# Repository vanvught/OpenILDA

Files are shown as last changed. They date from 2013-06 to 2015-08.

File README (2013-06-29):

---> WORK IN PROGRESS <---

OpenILDA
========

Cheap ILDA SPI DAC board for Raspberry Pi. 

ILDA output: balanced X/Y - 12 bit,  balanced R/G/B/I - 8 bit.

Playback of ILDA files from external SD card.

OSC support (using RPi <- UART/USB -> PC[java] <- UDP-> iPad/iPod)

This OpenILDA DAC board uses the SPI interface for controlling 3 DAC's. The MCP49x2 device is a dual channel DAC.
As the RPi just has 2 SPI chip enable lines, the DAC /CS lines are created by using a HC139 See viewtopic.php?p=333992#p333992

Of course, I could have used a 12-bit 8-channel DAC (for example TLV5610IDW). This would create less components. However, such a DAC is relatively expensive (24 Euro) and it would have a SO-20 package.

I will post the OpenILDA sd-card player with OSC support (written for bare-metal) soon.

What's next? ()
*. Reduce the amount of OPAMP's (from 6 to 3)
*. Enable using single voltage power supply
	- Use DC/DC converter for -12 volt / +12 volt
	- Use 7805 for 5 volt output voltage
	
See also http://www.raspberrypi.org/phpBB3/viewtopic.php?p=366647#p366647

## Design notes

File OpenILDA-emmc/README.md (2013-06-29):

FILES
  ffconf.h   Configuration file for FatFs module.
  ff.h       Common include file for FatFs and application module.
  ff.c       FatFs module.
  diskio.h   Common include file for FatFs and disk I/O modul.
  diskio.c   An example of glue function to attach existing disk I/O module to FatFs.
  integer.h  Integer type definitions for FatFs.

  bcm2835.c  Mike's library ported for bare-metal
  mmcbb.c    Low level disk I/O module for Rasberry Pi
  vectors.s  Copyright (c) 2012 David Welch dwelch@dwelch.com
  syscalls.c Support file for GNU libc.  

AGREEMENTS

FatFs module is an open source software to implement FAT file system to
small embedded systems. This is a free software and is opened for education,
research and commercial developments under license policy of following trems.

Copyright (C) 2012, ChaN, all right reserved.

 * The FatFs module is a free software and there is NO WARRANTY.
 * No restriction on use. You can use, modify and redistribute it for
   personal, non-profit or commercial product UNDER YOUR RESPONSIBILITY.
 * Redistributions of source code must retain the above copyright notice.

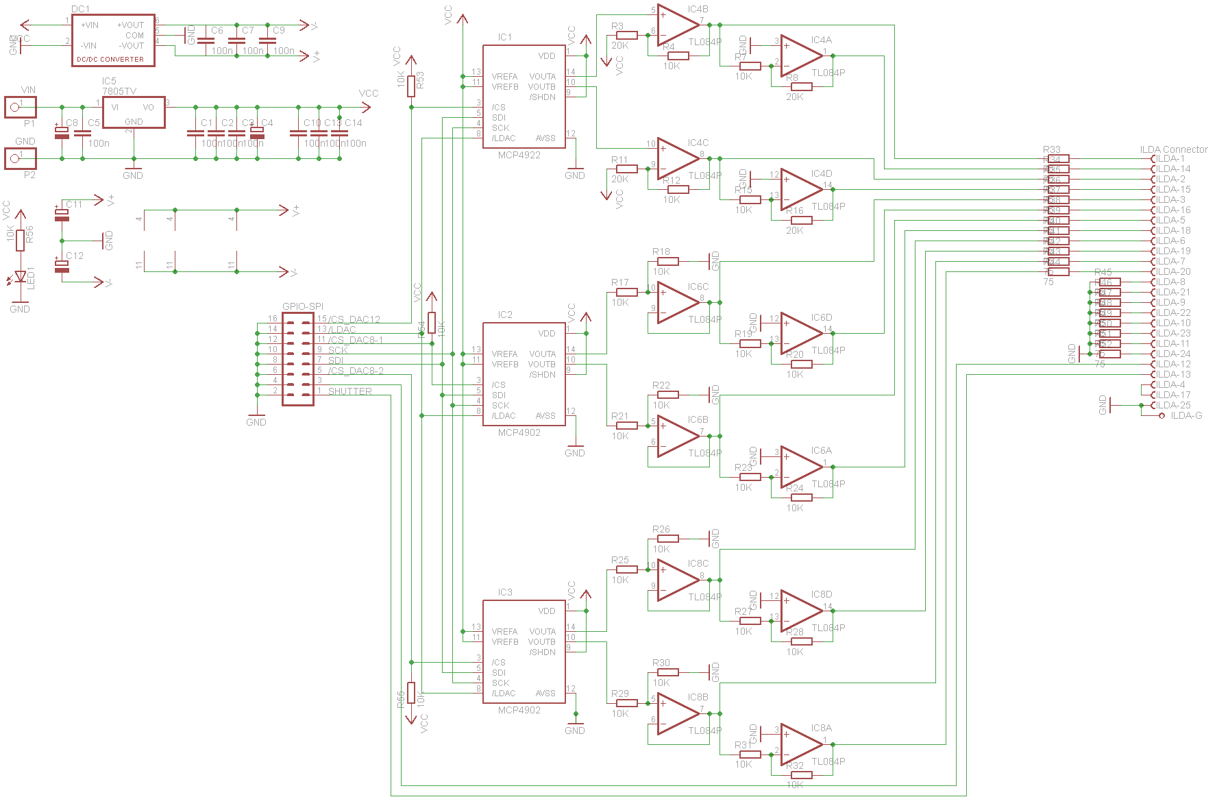
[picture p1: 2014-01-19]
Eagle/Rpi-ILDA-DAC_sch.png

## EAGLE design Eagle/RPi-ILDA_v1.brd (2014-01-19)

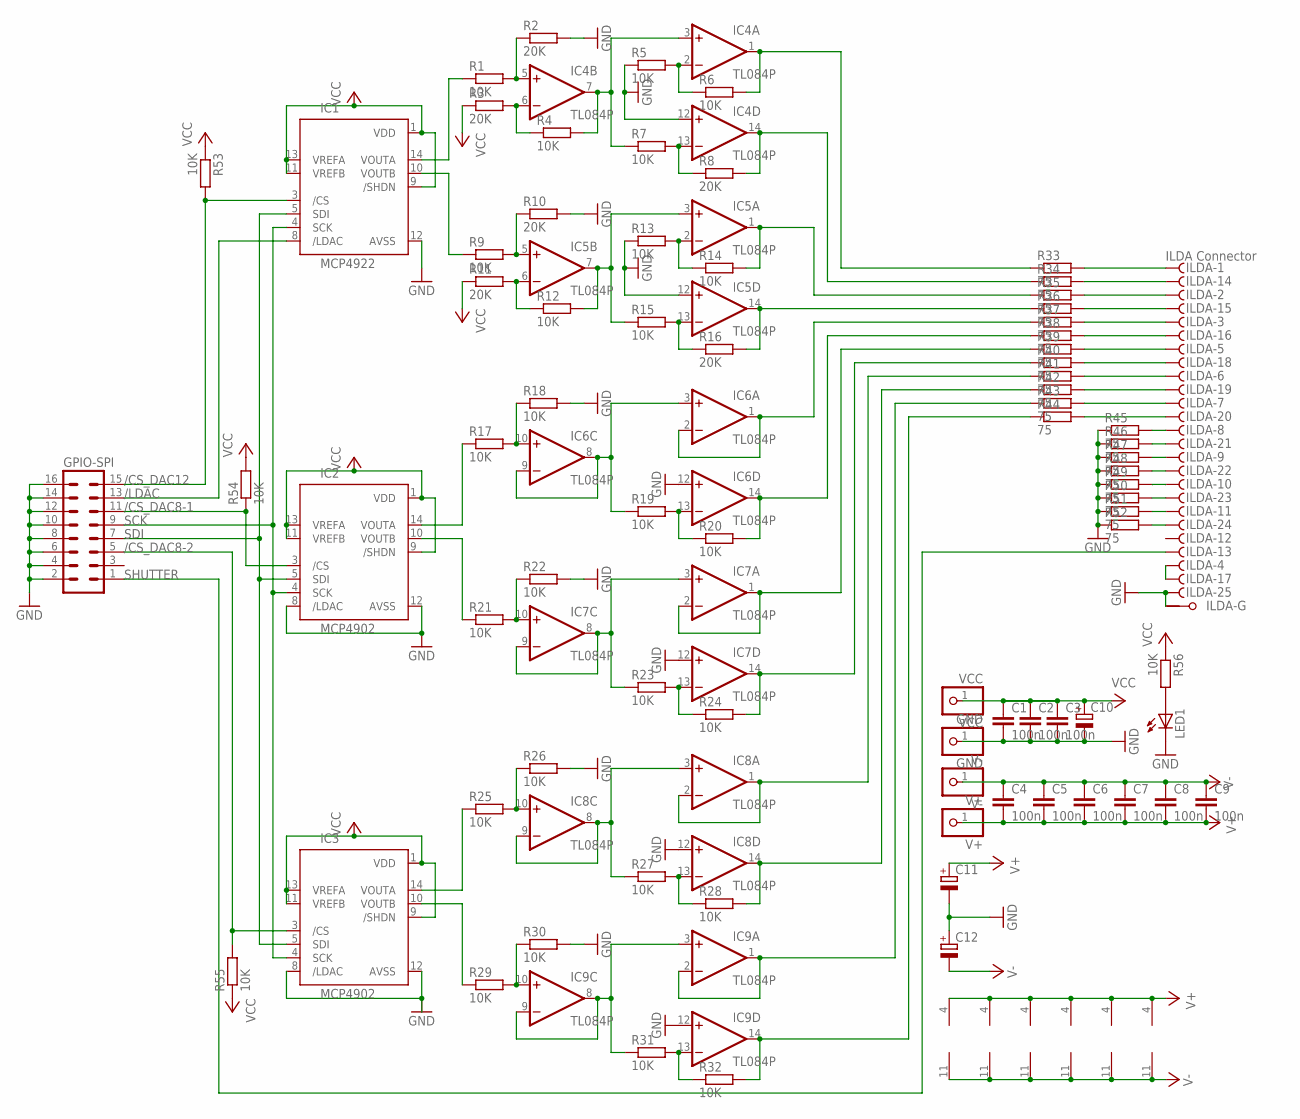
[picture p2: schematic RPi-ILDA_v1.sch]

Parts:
C1, C2, C3, C4, C5, C6, C7, C8, C9: 100n; C050-024X044
C10, C11, C12: CPOL-EUE5-6; E5-6
GND: GND; 1X01
GPIO-SPI: MA08-2
IC1: MCP4922; DIL14
IC2, IC3: MCP4902; DIL14
IC4, IC5, IC6, IC7, IC8, IC9: TL084P; DIL14
ILDA: ILDA Connector; F25HP
LED1: LED3MM
R1, R7, R9, R15, R17, R21, R22, R25, R29, R30, R53, R54, R55: 10K; 0204/5
R2, R8, R10, R16: 20K; 0204V
R3, R11: 20K; 0204/5
R4, R5, R6, R12, R13, R14, R18, R19, R20, R23, R24, R26, R27, R28, R31, R32, R56: 10K; 0204V
R33, R34, R35, R36, R37, R38, R39, R40, R41, R42, R43, R44, R45, R46, R47, R48, R49, R50, R51, R52: 75; 0204V
V+: V+; 1X01
V-: V-; 1X01
VCC: VCC; 1X01

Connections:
/CS_DAC8-1: GPIO-SPI.11, IC2.3 (/CS), R54.1
/CS_DAC8-2: GPIO-SPI.5, IC3.3 (/CS), R55.2
/CS_DAC12: GPIO-SPI.15, IC1.3 (/CS), R53.2
/LDAC: GPIO-SPI.13, IC1.8 (/LDAC)
GND: C1.2, C2.2, C3.2, C10.-, C11.-, C12.+, GND.1, GPIO-SPI.2, GPIO-SPI.4, GPIO-SPI.6, GPIO-SPI.8, GPIO-SPI.10, GPIO-SPI.12, GPIO-SPI.14, GPIO-SPI.16, IC1.12 (AVSS), IC2.8 (/LDAC), IC2.12 (AVSS), IC3.8 (/LDAC), IC3.12 (AVSS), IC4.12 (+IN), IC5.12 (+IN), IC6.12 (+IN), IC7.12 (+IN), IC8.12 (+IN), IC9.12 (+IN), ILDA.25 (F), ILDA.G1, LED1.K (C), R2.2, R5.1, R10.2, R13.1, R18.2, R22.2, R26.2, R30.2, R45.1, R46.1, R47.1, R48.1, R49.1, R50.1, R51.1, R52.1
unnamed: LED1.A, R56.2
unnamed: ILDA.3 (F), R37.2
unnamed: IC4.2 (-IN), R5.2, R6.1
unnamed: IC5.2 (-IN), R13.2, R14.1
unnamed: IC5.13 (-IN), R15.2, R16.1
unnamed: IC3.14 (VOUTA), R25.1
unnamed: IC7.14 (OUT), R24.2, R40.1
unnamed: IC7.13 (-IN), R23.2, R24.1
unnamed: IC7.10 (+IN), R21.2, R22.1
unnamed: ILDA.4 (F), ILDA.17 (F)
unnamed: IC7.3 (+IN), IC7.8 (OUT), IC7.9 (-IN), R23.1
unnamed: IC7.1 (OUT), IC7.2 (-IN), R39.1
unnamed: ILDA.5 (F), R39.2
unnamed: IC1.14 (VOUTA), R1.1
unnamed: IC1.10 (VOUTB), R9.1
unnamed: ILDA.18 (F), R40.2
unnamed: IC6.14 (OUT), R20.2, R38.1
unnamed: IC4.13 (-IN), R7.2, R8.1
unnamed: IC6.13 (-IN), R19.2, R20.1
unnamed: IC8.14 (OUT), R28.2, R42.1
unnamed: IC6.10 (+IN), R17.2, R18.1
unnamed: IC6.3 (+IN), IC6.8 (OUT), IC6.9 (-IN), R19.1
unnamed: IC6.1 (OUT), IC6.2 (-IN), R37.1
unnamed: IC8.13 (-IN), R27.2, R28.1
unnamed: IC8.10 (+IN), R25.2, R26.1
unnamed: IC8.3 (+IN), IC8.8 (OUT), IC8.9 (-IN), R27.1
unnamed: IC8.1 (OUT), IC8.2 (-IN), R41.1
unnamed: ILDA.8 (F), R45.2
unnamed: ILDA.6 (F), R41.2
unnamed: ILDA.16 (F), R38.2
unnamed: IC5.14 (OUT), R16.2, R36.1
unnamed: ILDA.19 (F), R42.2
unnamed: IC5.1 (OUT), R14.2, R35.1
unnamed: IC9.14 (OUT), R32.2, R44.1
unnamed: IC9.13 (-IN), R31.2, R32.1
unnamed: IC9.10 (+IN), R29.2, R30.1
unnamed: IC9.3 (+IN), IC9.8 (OUT), IC9.9 (-IN), R31.1
unnamed: IC9.1 (OUT), IC9.2 (-IN), R43.1
unnamed: IC3.10 (VOUTB), R29.1
unnamed: IC4.14 (OUT), R8.2, R34.1
unnamed: IC4.1 (OUT), R6.2, R33.1
unnamed: IC5.3 (+IN), IC5.7 (OUT), R12.2, R15.1
unnamed: IC4.6 (-IN), R3.2, R4.1
unnamed: IC5.6 (-IN), R11.2, R12.1
unnamed: ILDA.7 (F), R43.2
unnamed: ILDA.20 (F), R44.2
unnamed: ILDA.21 (F), R46.2
unnamed: ILDA.9 (F), R47.2
unnamed: ILDA.22 (F), R48.2
unnamed: ILDA.10 (F), R49.2
unnamed: ILDA.23 (F), R50.2
unnamed: IC2.14 (VOUTA), R17.1
unnamed: ILDA.11 (F), R51.2
unnamed: ILDA.24 (F), R52.2
unnamed: IC2.10 (VOUTB), R21.1
unnamed: IC5.5 (+IN), R9.2, R10.1
unnamed: IC4.5 (+IN), R1.2, R2.1
unnamed: IC4.3 (+IN), IC4.7 (OUT), R4.2, R7.1
unnamed: ILDA.1 (F), R33.2
unnamed: ILDA.14 (F), R34.2
unnamed: ILDA.15 (F), R36.2
unnamed: ILDA.2 (F), R35.2
SCK: GPIO-SPI.9, IC1.4 (SCK), IC2.4 (SCK), IC3.4 (SCK)
SDI: GPIO-SPI.7, IC1.5 (SDI), IC2.5 (SDI), IC3.5 (SDI)
SHUTTER: GPIO-SPI.1, ILDA.13 (F)
V+: C4.2, C5.2, C6.2, C7.2, C8.2, C9.2, C11.+, IC4.4 (V+), IC5.4 (V+), IC6.4 (V+), IC7.4 (V+), IC8.4 (V+), IC9.4 (V+), V+.1
V-: C4.1, C5.1, C6.1, C7.1, C8.1, C9.1, C12.-, IC4.11 (V-), IC5.11 (V-), IC6.11 (V-), IC7.11 (V-), IC8.11 (V-), IC9.11 (V-), V-.1
VCC: C1.1, C2.1, C3.1, C10.+, IC1.1 (VDD), IC1.9 (/SHDN), IC1.11 (VREFB), IC1.13 (VREFA), IC2.1 (VDD), IC2.9 (/SHDN), IC2.11 (VREFB), IC2.13 (VREFA), IC3.1 (VDD), IC3.9 (/SHDN), IC3.11 (VREFB), IC3.13 (VREFA), R3.1, R11.1, R53.1, R54.2, R55.1, R56.1, VCC.1

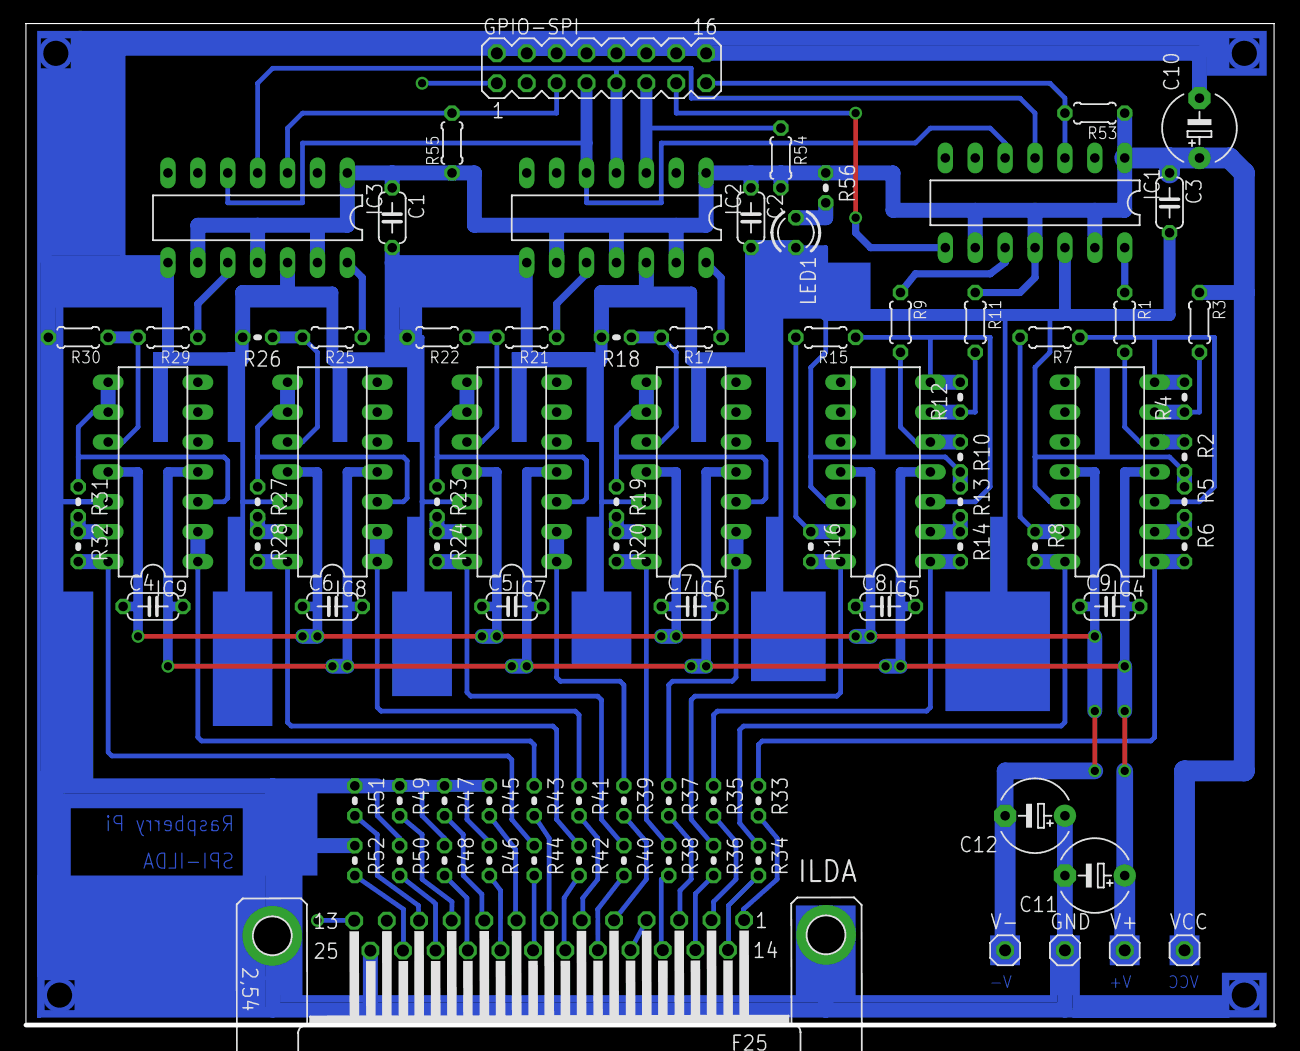
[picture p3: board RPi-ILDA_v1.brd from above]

Board: 2 copper layers, 106.0 x 85.1 mm, 84 parts (0 on the bottom side), 73 nets.

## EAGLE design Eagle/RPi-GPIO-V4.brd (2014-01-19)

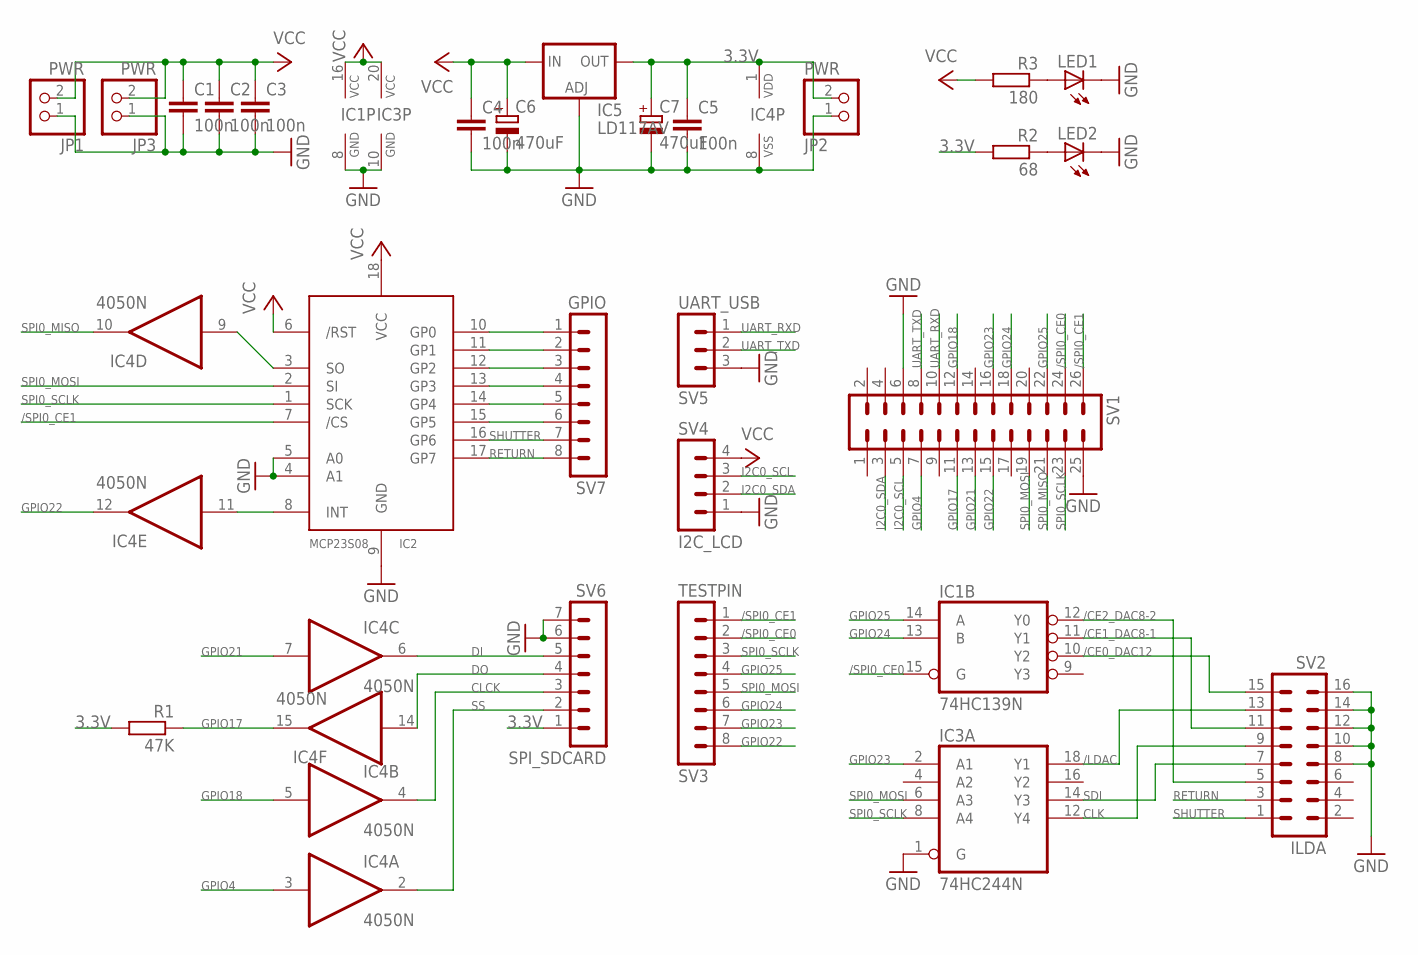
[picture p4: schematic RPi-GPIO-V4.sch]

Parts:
C1, C2, C3, C4, C5: 100n; C050-024X044
C6, C7: 470uF; E5-8,5
IC1: 74HC139N; DIL16
IC2: MCP2300X/P; DIL18
IC3: 74HC244N; DIL20
IC4: 4050N; DIL16
IC5: LD117AV; TO220L1
JP1, JP2, JP3: PWR; 1X02
LED1, LED2: LED3MM
R1: 47K; 0204/5
R2: 68; 0204/5
R3: 180; 0204/5
SV1: MA13-2
SV2: ILDA; MA08-2
SV3: TESTPIN; MA08-1
SV4: I2C_LCD; MA04-1
SV5: UART_USB; MA03-1
SV6: SPI_SDCARD; MA07-1
SV7: GPIO; MA08-1

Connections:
3.3V: C5.1, C7.+, IC4.1 (VDD), IC5.2 (OUT), JP2.2, R1.2, R2.2, SV6.1
/CE0_DAC12: IC1.10 (Y2), SV2.15
/CE1_DAC8-1: IC1.11 (Y1), SV2.11
/CE2_DAC8-2: IC1.12 (Y0), SV2.5
/LDAC: IC3.18 (Y1), SV2.13
/SPI0_CE0: IC1.15 (G), SV1.24, SV3.2
/SPI0_CE1: IC2.7 (/CS), SV1.26, SV3.1
CLCK: IC4.4 (O), SV6.3
CLK: IC3.12 (Y4), SV2.9
DI: IC4.6 (O), SV6.5
DO: IC4.14 (I), SV6.4
GND: C1.2, C2.2, C3.2, C4.2, C5.2, C6.-, C7.-, IC1.8 (GND), IC2.4 (A1), IC2.5 (A0), IC2.9 (GND), IC3.1 (G), IC3.10 (GND), IC4.8 (VSS), IC5.1 (ADJ), JP1.1, JP2.1, JP3.1, LED1.K (C), LED2.K (C), SV1.6, SV1.25, SV2.8, SV2.10, SV2.12, SV2.14, SV2.16, SV4.1, SV5.3, SV6.6, SV6.7
GPIO4: IC4.3 (I), SV1.7
GPIO17: IC4.15 (O), R1.1, SV1.11
GPIO18: IC4.5 (I), SV1.12
GPIO21: IC4.7 (I), SV1.13
GPIO22: IC4.12 (O), SV1.15, SV3.8
GPIO23: IC3.2 (A1), SV1.16, SV3.7
GPIO24: IC1.13 (B), SV1.18, SV3.6
GPIO25: IC1.14 (A), SV1.22, SV3.4
I2C0_SCL: SV1.5, SV4.3
I2C0_SDA: SV1.3, SV4.2
unnamed: LED1.A, R3.1
unnamed: LED2.A, R2.1
unnamed: IC2.3 (SO), IC4.9 (I)
unnamed: IC2.10 (GP0), SV7.1
unnamed: IC2.11 (GP1), SV7.2
unnamed: IC2.12 (GP2), SV7.3
unnamed: IC2.13 (GP3), SV7.4
unnamed: IC2.14 (GP4), SV7.5
unnamed: IC2.15 (GP5), SV7.6
unnamed: IC2.8 (INT), IC4.11 (I)
RETURN: IC2.17 (GP7), SV2.3, SV7.8
SDI: IC3.14 (Y3), SV2.7
SHUTTER: IC2.16 (GP6), SV2.1, SV7.7
SPI0_MISO: IC4.10 (O), SV1.21
SPI0_MOSI: IC2.2 (SI), IC3.6 (A3), SV1.19, SV3.5
SPI0_SCLK: IC2.1 (SCK), IC3.8 (A4), SV1.23, SV3.3
SS: IC4.2 (O), SV6.2
UART_RXD: SV1.10, SV5.1
UART_TXD: SV1.8, SV5.2
VCC: C1.1, C2.1, C3.1, C4.1, C6.+, IC1.16 (VCC), IC2.6 (/RST), IC2.18 (VCC), IC3.20 (VCC), IC5.3 (IN), JP1.2, JP3.2, R3.2, SV4.4

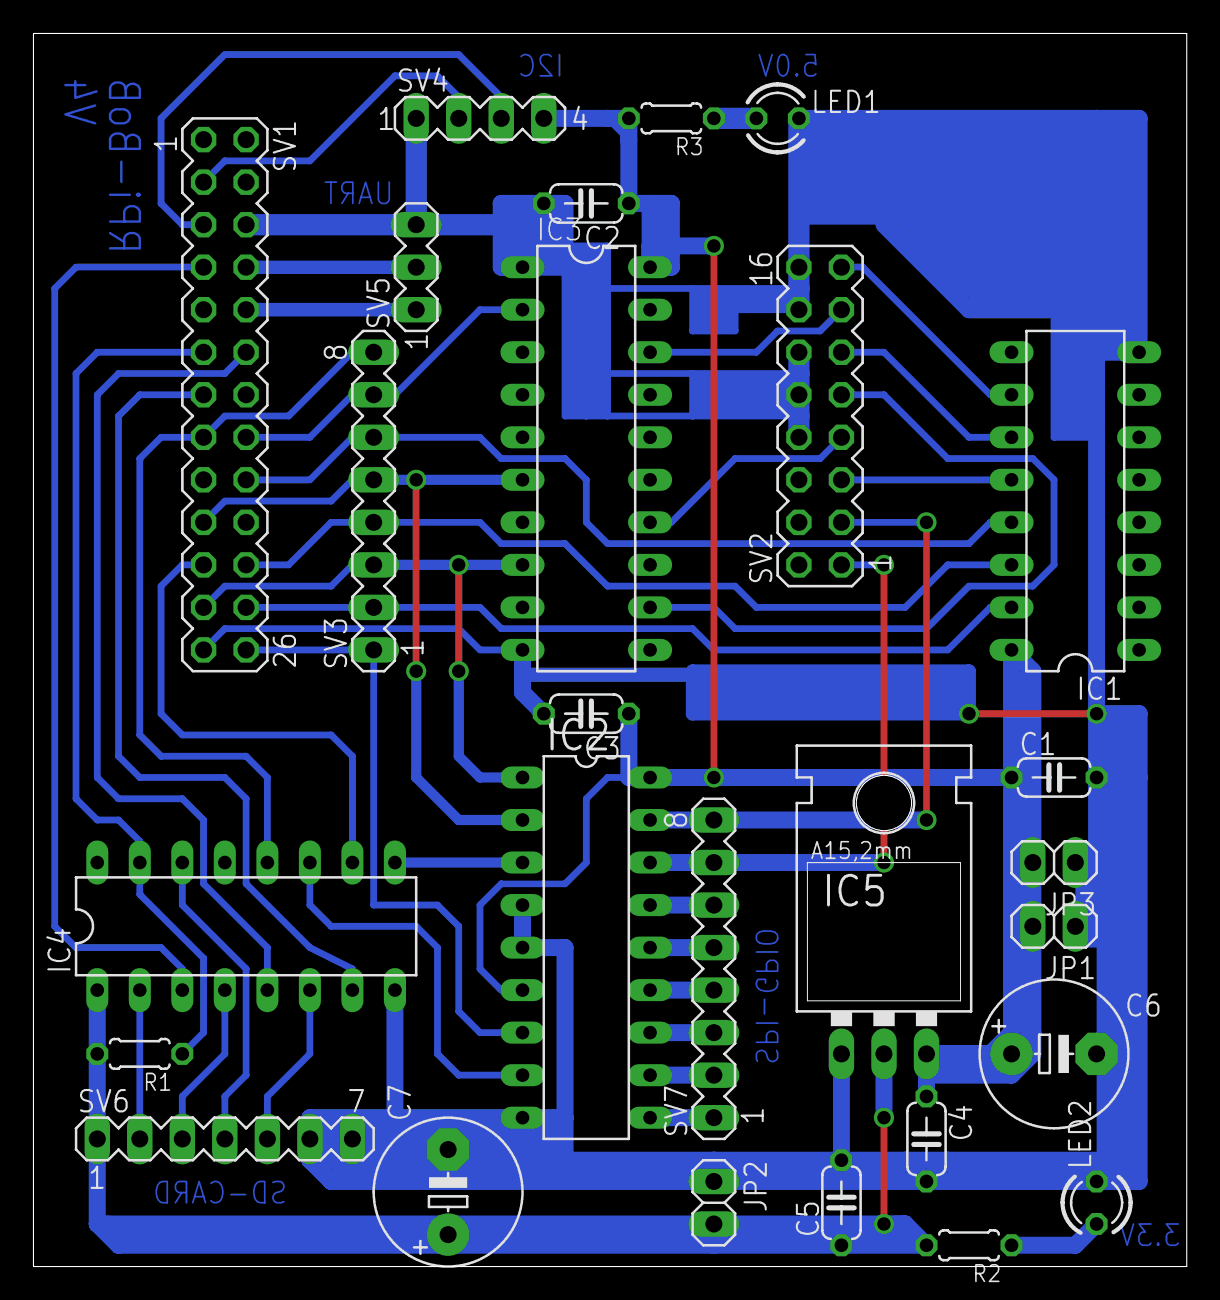
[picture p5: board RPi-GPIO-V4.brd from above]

Board: 2 copper layers, 68.9 x 73.7 mm, 27 parts (0 on the bottom side), 42 nets.

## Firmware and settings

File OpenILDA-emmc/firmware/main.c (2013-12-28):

#include <LPC17xx.h>
#include <serial.h>
#include "ether.h"
#include <lwip/init.h>
#include <lwip/tcp.h>
#include <lwip/dhcp.h>
#include <ipv4/lwip/autoip.h>
#include <string.h>
#include <broadcast.h>
#include <assert.h>
#include <attrib.h>
#include <lightengine.h>
#include <skub.h>
#include <tables.h>
#include <playback.h>
#include <dac.h>
#include <hardware.h>
#include <file_player.h>
#include <dac_settings.h>

#include <bcm2835.h>

struct {
	volatile uint32_t time;
	volatile uint8_t mtime;
} clock;
//extern int f0ad_flag;
//extern const char build[];

dac_settings_t settings;
#if 0
void SysTick_Handler(void) {
	uint8_t mtime_buf = clock.mtime + 1;

	if (hw_board_rev == HW_REV_MP2 && le_state != LIGHTENGINE_ESTOP) {
		if (mtime_buf % 2)
			LPC_GPIO2->FIOSET = (1 << 8);
		else
			LPC_GPIO2->FIOCLR = (1 << 8);
	}

	if (mtime_buf < 10) {
		clock.mtime = mtime_buf;
		return;
	}

	clock.mtime = 0;
	uint32_t time = clock.time;
	clock.time = time + 1;

	/* If we're in an estop condition, slow-blink the LED */
	if (time % 512 == 0) {
		led_set_frontled(1);
	} else if (time % 512 == 450 && le_state == LIGHTENGINE_ESTOP) {
		led_set_frontled(0);
	}
}
#endif
extern void print_dac_cycle_count(void);

//extern void dmx_in_poll(void);

struct periodic_event {
	void (*f)(void);
	int period;
	const char *msg;
	int start;
} const events[] = {
//	{ tcp_tmr, 250, "tcp", 100 },
//	{ ip_reass_tmr, 1000, "ip_reass", 17 },
//	{ etharp_tmr, 5000, "ip_reass", 177 },
//	{ dhcp_coarse_tmr, 60000, "dhcp c", 35 },
//	{ dmx_in_poll, 25, "dmx", 4 },
//	{ dhcp_fine_tmr, 500, "dhcp f", 25 },
//	{ autoip_tmr, AUTOIP_TMR_INTERVAL, "autoip", 10 },
//	{ broadcast_send, 1000, "broadcast", 10 },
#if DAC_INSTRUMENT_TIME
	{ print_dac_cycle_count, 1000000, "dac_cycle_count", 4 },
#endif
//	{ eth_check_link, 100, "eth_check_link", 2 },
};

int events_last[sizeof(events) / sizeof(events[0])];

TABLE(initializer_t, protocol);
TABLE(initializer_t, hardware);
TABLE(initializer_t, poll);

static void COLD NOINLINE FPA_init() {
	int i;

	debugf("### Initializing Hardware ###\r\n");

	for (i = 0; i < TABLE_LENGTH(hardware); i++) {
		outputf("- %s()", hardware_table[i].name);
		hardware_table[i].f();
	}

	debugf("### Initializing Protocols ###\r\n");

	for (i = 0; i < TABLE_LENGTH(protocol); i++) {
		outputf("- %s()", protocol_table[i].name);
		protocol_table[i].f();
	}
}

void check_periodic_timers() {
	int i;
	clock.time = bcm2835_st_read();
	for (i = 0; i < (sizeof(events) / sizeof(events[0])); i++) {
		if (clock.time > events_last[i] + events[i].period) {
			events[i].f();
			events_last[i] += events[i].period;
			watchdog_feed();
		}
	}
}

#ifdef ENABLE_FRAMEBUFFER
extern void bcm2835_console_begin(void);
#endif

int notmain (void)
{
	__disable_irq();
	__disable_fiq();

	bcm2835_uart_begin();

#ifdef ENABLE_FRAMEBUFFER
	bcm2835_console_begin();
#endif

	debugf("Starting up: led\r\n");
	led_init();
	led_set_frontled(1);

	/* Initialize hardware */
	FPA_init();

	outputf("Entering main loop...");
	watchdog_init();

	/* Startup might have taken some time, so reset the periodic event
	 * timers. */
	int i;
	clock.time = bcm2835_st_read();
	for (i = 0; i < (sizeof(events) / sizeof(events[0])); i++) {
		events_last[i] = events[i].start + clock.time;
	}

	__enable_irq();
	//__enable_fiq();

	playback_set_src(SRC_ILDAPLAYER);

	/* Default values */
	dac_set_rate(1000);
	ilda_set_fps_limit(5);

	while(1) {
		watchdog_feed();

		/* Check the stuff we check on each loop iteration. */
		for (i = 0; i < TABLE_LENGTH(poll); i++) {
			poll_table[i].f();
		}

		/* Check for periodic events */
		check_periodic_timers();
	}

	return 0;
}

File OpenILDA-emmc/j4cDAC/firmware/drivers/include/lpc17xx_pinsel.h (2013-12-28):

/***********************************************************************//**
 * @file		lpc17xx_pinsel.h
 * @brief		Contains all macro definitions and function prototypes
 * 				support for Pin connect block firmware library on LPC17xx
 * @version		2.0
 * @date		21. May. 2010
 * @author		NXP MCU SW Application Team
 **************************************************************************
 * Software that is described herein is for illustrative purposes only
 * which provides customers with programming information regarding the
 * products. This software is supplied "AS IS" without any warranties.
 * NXP Semiconductors assumes no responsibility or liability for the
 * use of the software, conveys no license or title under any patent,
 * copyright, or mask work right to the product. NXP Semiconductors
 * reserves the right to make changes in the software without
 * notification. NXP Semiconductors also make no representation or
 * warranty that such application will be suitable for the specified
 * use without further testing or modification.
 **************************************************************************/

/* Peripheral group ----------------------------------------------------------- */
/** @defgroup PINSEL PINSEL
 * @ingroup LPC1700CMSIS_FwLib_Drivers
 * @{
 */

#ifndef LPC17XX_PINSEL_H_
#define LPC17XX_PINSEL_H_

/* Includes ------------------------------------------------------------------- */
#include "LPC17xx.h"
#include "lpc_types.h"

#ifdef __cplusplus
extern "C"
{
#endif

/* Public Macros -------------------------------------------------------------- */
/** @defgroup PINSEL_Public_Macros PINSEL Public Macros
 * @{
 */

/*********************************************************************//**
 *!< Macros define for PORT Selection
 ***********************************************************************/
#define PINSEL_PORT_0 	((0))	/**< PORT 0*/
#define PINSEL_PORT_1 	((1))	/**< PORT 1*/
#define PINSEL_PORT_2 	((2))	/**< PORT 2*/
#define PINSEL_PORT_3 	((3))	/**< PORT 3*/
#define PINSEL_PORT_4 	((4))	/**< PORT 4*/

/***********************************************************************
 * Macros define for Pin Function selection
 **********************************************************************/
#define PINSEL_FUNC_0	((0))	/**< default function*/
#define PINSEL_FUNC_1	((1))	/**< first alternate function*/
#define PINSEL_FUNC_2	((2))	/**< second alternate function*/
#define PINSEL_FUNC_3	((3))	/**< third or reserved alternate function*/

/***********************************************************************
 * Macros define for Pin Number of Port
 **********************************************************************/
#define PINSEL_PIN_0 	((0)) 	/**< Pin 0 */
#define PINSEL_PIN_1 	((1)) 	/**< Pin 1 */
#define PINSEL_PIN_2 	((2)) 	/**< Pin 2 */
#define PINSEL_PIN_3 	((3)) 	/**< Pin 3 */
#define PINSEL_PIN_4 	((4)) 	/**< Pin 4 */
#define PINSEL_PIN_5 	((5)) 	/**< Pin 5 */
#define PINSEL_PIN_6 	((6)) 	/**< Pin 6 */
#define PINSEL_PIN_7 	((7)) 	/**< Pin 7 */
#define PINSEL_PIN_8 	((8)) 	/**< Pin 8 */
#define PINSEL_PIN_9 	((9)) 	/**< Pin 9 */
#define PINSEL_PIN_10 	((10)) 	/**< Pin 10 */
#define PINSEL_PIN_11 	((11)) 	/**< Pin 11 */
#define PINSEL_PIN_12 	((12)) 	/**< Pin 12 */
#define PINSEL_PIN_13 	((13)) 	/**< Pin 13 */
#define PINSEL_PIN_14 	((14)) 	/**< Pin 14 */
#define PINSEL_PIN_15 	((15)) 	/**< Pin 15 */
#define PINSEL_PIN_16 	((16)) 	/**< Pin 16 */
#define PINSEL_PIN_17 	((17)) 	/**< Pin 17 */
#define PINSEL_PIN_18 	((18)) 	/**< Pin 18 */
#define PINSEL_PIN_19 	((19)) 	/**< Pin 19 */
#define PINSEL_PIN_20 	((20)) 	/**< Pin 20 */
#define PINSEL_PIN_21 	((21)) 	/**< Pin 21 */
#define PINSEL_PIN_22 	((22)) 	/**< Pin 22 */
#define PINSEL_PIN_23 	((23)) 	/**< Pin 23 */
#define PINSEL_PIN_24 	((24)) 	/**< Pin 24 */
#define PINSEL_PIN_25 	((25)) 	/**< Pin 25 */
#define PINSEL_PIN_26 	((26)) 	/**< Pin 26 */
#define PINSEL_PIN_27 	((27)) 	/**< Pin 27 */
#define PINSEL_PIN_28 	((28)) 	/**< Pin 28 */
#define PINSEL_PIN_29 	((29)) 	/**< Pin 29 */
#define PINSEL_PIN_30 	((30)) 	/**< Pin 30 */
#define PINSEL_PIN_31 	((31)) 	/**< Pin 31 */

/***********************************************************************
 * Macros define for Pin mode
 **********************************************************************/
#define PINSEL_PINMODE_PULLUP		((0))	/**< Internal pull-up resistor*/
#define PINSEL_PINMODE_TRISTATE 	((2))	/**< Tri-state */
#define PINSEL_PINMODE_PULLDOWN 	((3)) 	/**< Internal pull-down resistor */

/***********************************************************************
 * Macros define for Pin mode (normal/open drain)
 **********************************************************************/
#define	PINSEL_PINMODE_NORMAL		((0))	/**< Pin is in the normal (not open drain) mode.*/
#define	PINSEL_PINMODE_OPENDRAIN	((1)) 	/**< Pin is in the open drain mode */
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

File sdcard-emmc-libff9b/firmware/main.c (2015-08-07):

#include <stdio.h>
#include <stdlib.h>

#include "hardware.h"
#include "ff.h"

FATFS Fatfs;		/* File system object */
FIL Fil;			/* File object */
BYTE Buff[128];		/* File read buffer */

void __attribute__((interrupt("IRQ"))) c_irq_handler(void) {}
void __attribute__((interrupt("FIQ"))) c_fiq_handler(void) {}


void die(FRESULT rc) {
	printf("Failed with rc=%d.\n", (int)rc);
	while (1)
		;
}

int notmain (void)
{
	FRESULT rc;				/* Result code */
	// DIR dir;				/* Directory object */
	// FILINFO fno;			/* File information object */
	// UINT br;

	hardware_init();

    printf("Compiled on %s at %s\n", __DATE__, __TIME__);
	printf("SD Card power state: %ld\n", bcm2835_vc_get_power_state(BCM2835_VC_POWER_ID_SDCARD));

	f_mount(0, &Fatfs);		/* Register volume work area (never fails) */

#if 1
	printf("\nOpen an existing file (params.txt).\n");
	rc = f_open(&Fil, "params.txt", FA_READ);
	if (rc)
		die(rc);

	printf("\nType the file content.\n");
	int i = 1;
	for (;;) {
		if (f_gets((TCHAR *)Buff, sizeof Buff, &Fil) == NULL)
			break; /* Error or end of file */
		printf("%d\t:%s\n", i, Buff);
		i++;
	}
	if (rc)
		die(rc);

	printf("\nClose the file.\n");
	rc = f_close(&Fil);
	if (rc)
		die(rc);
#endif

#if 0
	int i;
	printf("\nOpen an existing file (devices.txt).\n");
	rc = f_open(&Fil, "devices.txt", FA_READ);
	if (rc)
		die(rc);

	printf("\nType the file content.\n");
	for (;;) {
		rc = f_read(&Fil, Buff, sizeof Buff, &br); /* Read a chunk of file */
		if (rc || !br)
			break; /* Error or end of file */
		for (i = 0; i < br; i++) /* Type the data */
			putchar(Buff[i]);
	}
	if (rc)
		die(rc);

	printf("\nClose the file.\n");
	rc = f_close(&Fil);
	if (rc)
		die(rc);
#endif

#if 0
	UINT bw;
	printf("\nCreate a new file (hello.txt).\n");
	rc = f_open(&Fil, "hello.txt", FA_WRITE | FA_CREATE_ALWAYS);
	if (rc) die(rc);

	printf("\nWrite a text data. (Hello world!)\n");
	rc = f_write(&Fil, "Hello world!\n", 14, &bw);
	if (rc) die(rc);
	printf("%d bytes written.\n", bw);

	printf("\nClose the file.\n");
	rc = f_close(&Fil);
	if (rc) die(rc);
#endif

#if 0
	printf("\nOpen root directory.\n");
	rc = f_opendir(&dir, "");
	if (rc) die(rc);

	char filename_buf[32];

	printf("\nDirectory listing...\n");
	for (;;) {
		fno.lfname = filename_buf;
		fno.lfsize = sizeof(filename_buf);
		rc = f_readdir(&dir, &fno);		/* Read a directory item */
		if (rc || !fno.fname[0]) break;	/* Error or end of dir */
		if (fno.fattrib & AM_DIR)
			printf("   <dir>  %s\n", fno.fname);
		else {
			char * fn = *fno.lfname ? fno.lfname : fno.fname;
			printf("%8lu  %s\n", fno.fsize, (char *) fn);
		}
	}
	if (rc) die(rc);
#endif

	printf("SD Card power state: %ld\n", bcm2835_vc_get_power_state(BCM2835_VC_POWER_ID_SDCARD));
	printf("\nTest completed.\n");

	return 0;
}

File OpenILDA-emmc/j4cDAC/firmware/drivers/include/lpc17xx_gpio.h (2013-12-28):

/***********************************************************************//**
 * @file		lpc17xx_gpio.h
 * @brief		Contains all macro definitions and function prototypes
 * 				support for GPIO firmware library on LPC17xx
 * @version		3.0
 * @date		18. June. 2010
 * @author		NXP MCU SW Application Team
 **************************************************************************
 * Software that is described herein is for illustrative purposes only
 * which provides customers with programming information regarding the
 * products. This software is supplied "AS IS" without any warranties.
 * NXP Semiconductors assumes no responsibility or liability for the
 * use of the software, conveys no license or title under any patent,
 * copyright, or mask work right to the product. NXP Semiconductors
 * reserves the right to make changes in the software without
 * notification. NXP Semiconductors also make no representation or
 * warranty that such application will be suitable for the specified
 * use without further testing or modification.
 **************************************************************************/

/* Peripheral group ----------------------------------------------------------- */
/** @defgroup GPIO GPIO
 * @ingroup LPC1700CMSIS_FwLib_Drivers
 * @{
 */

#ifndef LPC17XX_GPIO_H_
#define LPC17XX_GPIO_H_

/* Includes ------------------------------------------------------------------- */
#include "LPC17xx.h"
#include "lpc_types.h"


#ifdef __cplusplus
extern "C"
{
#endif

/* Public Macros -------------------------------------------------------------- */
/** @defgroup GPIO_Public_Macros GPIO Public Macros
 * @{
 */

/** Fast GPIO port 0 byte accessible definition */
#define GPIO0_Byte	((GPIO_Byte_TypeDef *)(LPC_GPIO0_BASE))
/** Fast GPIO port 1 byte accessible definition */
#define GPIO1_Byte	((GPIO_Byte_TypeDef *)(LPC_GPIO1_BASE))
/** Fast GPIO port 2 byte accessible definition */
#define GPIO2_Byte	((GPIO_Byte_TypeDef *)(LPC_GPIO2_BASE))
/** Fast GPIO port 3 byte accessible definition */
#define GPIO3_Byte	((GPIO_Byte_TypeDef *)(LPC_GPIO3_BASE))
/** Fast GPIO port 4 byte accessible definition */
#define GPIO4_Byte	((GPIO_Byte_TypeDef *)(LPC_GPIO4_BASE))


/** Fast GPIO port 0 half-word accessible definition */
#define GPIO0_HalfWord	((GPIO_HalfWord_TypeDef *)(LPC_GPIO0_BASE))
/** Fast GPIO port 1 half-word accessible definition */
#define GPIO1_HalfWord	((GPIO_HalfWord_TypeDef *)(LPC_GPIO1_BASE))
/** Fast GPIO port 2 half-word accessible definition */
#define GPIO2_HalfWord	((GPIO_HalfWord_TypeDef *)(LPC_GPIO2_BASE))
/** Fast GPIO port 3 half-word accessible definition */
#define GPIO3_HalfWord	((GPIO_HalfWord_TypeDef *)(LPC_GPIO3_BASE))
/** Fast GPIO port 4 half-word accessible definition */
#define GPIO4_HalfWord	((GPIO_HalfWord_TypeDef *)(LPC_GPIO4_BASE))

/**
 * @}
 */

/* Public Types --------------------------------------------------------------- */
/** @defgroup GPIO_Public_Types GPIO Public Types
 * @{
 */

/**
 * @brief Fast GPIO port byte type definition
 */
typedef struct {
	__IO uint8_t FIODIR[4];		/**< FIO direction register in byte-align */
	   uint32_t RESERVED0[3];	/**< Reserved */
	__IO uint8_t FIOMASK[4];	/**< FIO mask register in byte-align */
	__IO uint8_t FIOPIN[4];		/**< FIO pin register in byte align */
	__IO uint8_t FIOSET[4];		/**< FIO set register in byte-align */
	__O  uint8_t FIOCLR[4];		/**< FIO clear register in byte-align */
} GPIO_Byte_TypeDef;


/**
 * @brief Fast GPIO port half-word type definition
 */
typedef struct {
	__IO uint16_t FIODIRL;		/**< FIO direction register lower halfword part */
	__IO uint16_t FIODIRU;		/**< FIO direction register upper halfword part */
	   uint32_t RESERVED0[3];	/**< Reserved */
	__IO uint16_t FIOMASKL;		/**< FIO mask register lower halfword part */
	__IO uint16_t FIOMASKU;		/**< FIO mask register upper halfword part */
	__IO uint16_t FIOPINL;		/**< FIO pin register lower halfword part */
	__IO uint16_t FIOPINU;		/**< FIO pin register upper halfword part */
	__IO uint16_t FIOSETL;		/**< FIO set register lower halfword part */
	__IO uint16_t FIOSETU;		/**< FIO set register upper halfword part */
	__O  uint16_t FIOCLRL;		/**< FIO clear register lower halfword part */
	__O  uint16_t FIOCLRU;		/**< FIO clear register upper halfword part */
} GPIO_HalfWord_TypeDef;

/**
 * @}
 */


/* Public Functions ----------------------------------------------------------- */
/** @defgroup GPIO_Public_Functions GPIO Public Functions
 * @{
 */

/* GPIO style ------------------------------- */
void GPIO_SetDir(uint8_t portNum, uint32_t bitValue, uint8_t dir);
void GPIO_SetValue(uint8_t portNum, uint32_t bitValue);
void GPIO_ClearValue(uint8_t portNum, uint32_t bitValue);
uint32_t GPIO_ReadValue(uint8_t portNum);
void GPIO_IntCmd(uint8_t portNum, uint32_t bitValue, uint8_t edgeState);
FunctionalState GPIO_GetIntStatus(uint8_t portNum, uint32_t pinNum, uint8_t edgeState);
void GPIO_ClearInt(uint8_t portNum, uint32_t bitValue);
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

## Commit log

2013-07-11 Removed bcm2835_spi_mcp49x2 prototypes
2013-12-27 i2c routine NACK reset
2014-01-05 main.c renamed to i2cdetect.c
2014-01-19 Eagle files added again
    [RPi-GPIO-V4.brd, RPi-GPIO-V4.sch, RPi-ILDA-DAC.brd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]
2014-01-19 BitWizard multiple same devices support added
2014-01-31 Displaying (EMMC, UART, ARM, CORE) clock rates
2014-10-26 Identifying the Device bug fixed
2014-11-02 Added all BW devices
2014-11-03 BitWizard i2c_dio support added
2015-01-01 Minor cleanup for I2C SlaveAddress
2015-07-11 Support for Raspberry Pi 2
2015-07-11 Support for Raspberry Pi Model 2B
